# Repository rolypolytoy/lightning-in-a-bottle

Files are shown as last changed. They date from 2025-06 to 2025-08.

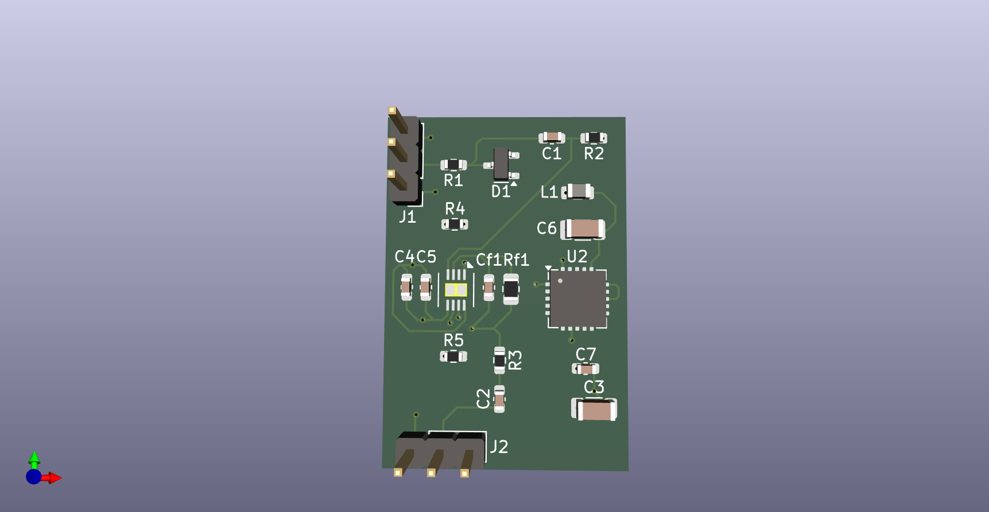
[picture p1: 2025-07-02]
csa.png

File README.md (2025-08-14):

# Lightning In A Bottle

Lightning in a bottle is an open-source, low-cost charge sensitive amplifier with several improvements over all existing commercial designs.

It has a >2x lower cost, a 750x greater gain, >5x greater bandwidth, >50% lower cost, and sub-5 dB lower SNR. Importantly- its real SNR will be higher since the gain is >750x, and since ADCs have noise, our gain will basically reduce that noise by 750x, and **so in real systems our CSA will have a much higher SNR than Cremat's module**, and thus this has no real 'weakness'. It also uses standard +5V as its power source rather than the weird +-6V-13V supplies the Cremat module needs.

It also uses commercial off-the-shelf components and so can be more easily and cheaply scaled than the Cremat CR-113 and other modules, whose components are proprietary and who may not ship to every country in the world in a timely manner.

Components:
- LMH6629SD, an ultra-low noise Op-Amp
- TPS7A3301RGW for power regulation
- Several miscellaneous ceramic capacitors, SMD resistors, inductors, and other generic components.

You can use a typical RC-CR pulse shaper or buy one from Cremat (might replace it soon but the CR-200-500ns arrived, so I don't need to make another one), but the specs of that are less important than the CSA setup. CSAs are better than transimpedance amplifiers for electron detection and nuclear research.

The [Cremat CR-113's datasheet](https://www.cremat.com/CR-113-R2.1.pdf) shows 18k electrons RMS baseline noise, 1.3 mV/pC gain and 30 electrons of noise RMS per pF, which means for the 0.01 microfarad AC coupled capacitor they show in their datasheet means they'll have around 300,000 electrons RMS of noise- which is a LOT of noise. Our SNR?

Op-amp voltage noise is 0.69 nV/√Hz (LMH6629), our feedback capacitor: Cf = 1pF, our feedback resistor: Rf = 10MΩ, our bandwidth: f = 1/(2π × Rf × Cf) = 1/(2π × 10MOhm × 1pF) = 15.9 kHz. Voltage noise is 0.69 nV/√Hz × √(15,900 Hz) = 0.69nV * 126 = 87 nV RMS voltage noise. Our gain is 1/Cf = 1/(1pF) = 1e12 V/C = 1000 mV/pC which is 750 times their gain. Our charge noise is thus 87nV / (1V/pC) = 87fC RMS, which is ~543,000 electrons, which is about a ~5 dB difference. 

Schematic file looks like:



PCB file looks like:



Gerbers, BOM and all manufacturing information is already there, and the project is in KiCAD's native file formats. It's a normal four-layer PCB with an estimated BOM of around $50/unit, which is less than half the price of a Cremat CR-113 module. 

## Charge Sensitive Amplifiers
Here's my attempt at explaining what a charge sensitive amplifier, written as a dialectic for my amusement (because who has the time to write a datasheet?)

A charge sensitive amplifier is basically just a capacitor around an op-amp. A capacitor is a thing which has capacitance, whereas an op-amp is something which makes voltage go up. I've made an informative schematic to fully get the concept across. 

OPAMPMAN

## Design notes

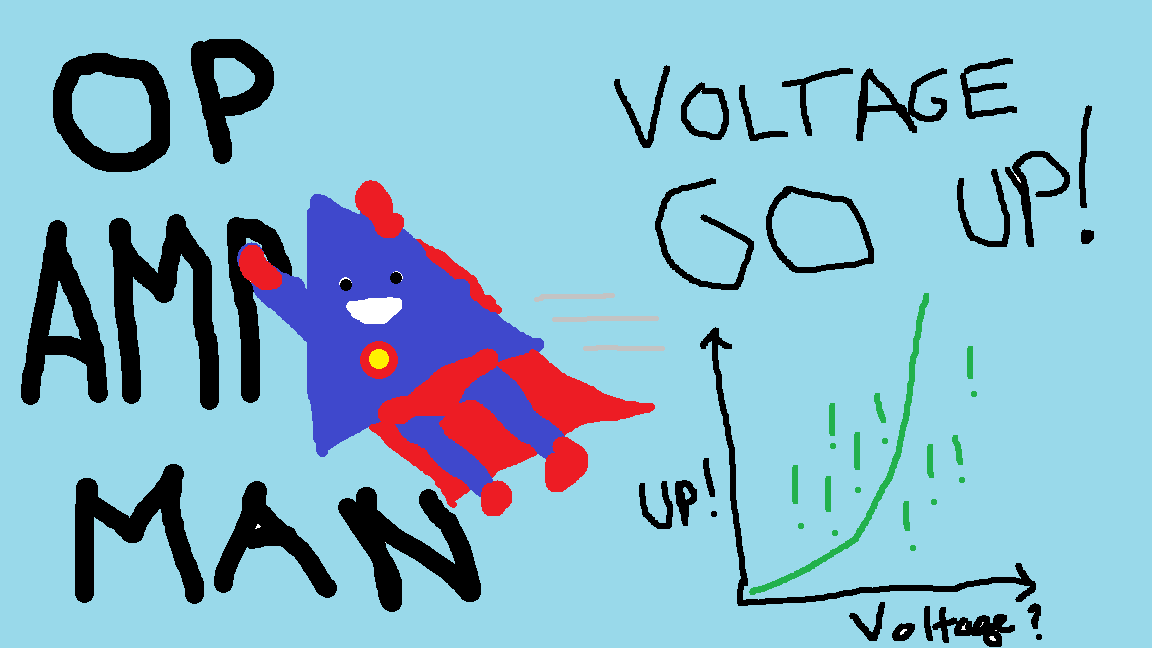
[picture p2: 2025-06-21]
OPAMPMAN.png

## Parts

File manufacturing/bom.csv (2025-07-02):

Id | Designator | Footprint | Quantity | Designation | MPN | Supplier/Notes
1 | C1,C2,C4 | C_0603_1608Metric | 3 | 100nF, 50V, X7R, ±10% | GCM188R71H104KA57D | Murata - 100nF 50V X7R 0603
2 | C3,C6 | C_1206_3216Metric | 2 | 10μF, 25V, X7R, ±10% | GRM31CR71E106KA12K | Murata - 10uF 25V X7R 1206
3 | U2 | Texas_RGW0020A_VQFN-20-1EP_5x5mm_P0.65mm_EP3.15x3.15mm_ThermalVias | 1 | TPS7A3301RGW | TPS7A3301RGWR | Texas Instruments - LDO Regulator (VERIFIED)
4 | C7 | C_0603_1608Metric | 1 | 1μF, 25V, X7R, ±10% | GCM188R71E105KA64D | Murata - 1uF 25V X7R 0603
5 | Cf1 | C_0603_1608Metric | 1 | 1pF, 50V, C0G/NP0, ±5% | GRM1885C1H1R0BA01D | Murata - 1pF 50V C0G/NP0 0603 precision cap
6 | U1 | WSON-8-1EP_3x3mm_P0.5mm_EP1.2x2mm | 1 | LMH6629SD/NOPB | LMH6629SD/NOPB | Texas Instruments - Op Amp (VERIFIED)
7 | R4,R5 | R_0603_1608Metric | 2 | 10KΩ, ±1%, 1/10W | RC0603FR-0710KL | Yageo - 10K ohm 1% 0603
8 | Rf1 | R_0805_2012Metric | 1 | 10MΩ, ±1%, 1/8W | CRCW080510M0FKEA | Vishay - 10M ohm 1% 0805
9 | C5 | C_0603_1608Metric | 1 | 1nF, 50V, X7R, ±10% | GCM188R71H102KA37D | Murata - 1nF 50V X7R 0603
10 | J2,J1 | PinHeader_1x03_P2.54mm_Vertical | 2 | Pin Header 1x03, 2.54mm pitch | PEC03SAAN | Sullins - 3-pin header 2.54mm pitch
11 | R3 | R_0603_1608Metric | 1 | 50Ω, ±1%, 1/10W | RC0603FR-0750RL | Yageo - 50 ohm 1% 0603
12 | D1 | SOT-23 | 1 | HSMS-2820 | HSMS-2820-TR1G | Broadcom/Avago - RF Schottky Diode (T&R packaging)
13 | L1 | L_0805_2012Metric | 1 | 10μH, ±20%, 0.5A | CB2012T100KR | Taiyo Yuden - 10uH 10% 0805 (VERIFIED - better tolerance)
14 | R2 | R_0603_1608Metric | 1 | 1MΩ, ±1%, 1/10W | RC0603FR-071ML | Yageo - 1M ohm 1% 0603
15 | R1 | R_0603_1608Metric | 1 | 1KΩ, ±1%, 1/10W | RC0603FR-071KL | Yageo - 1K ohm 1% 0603

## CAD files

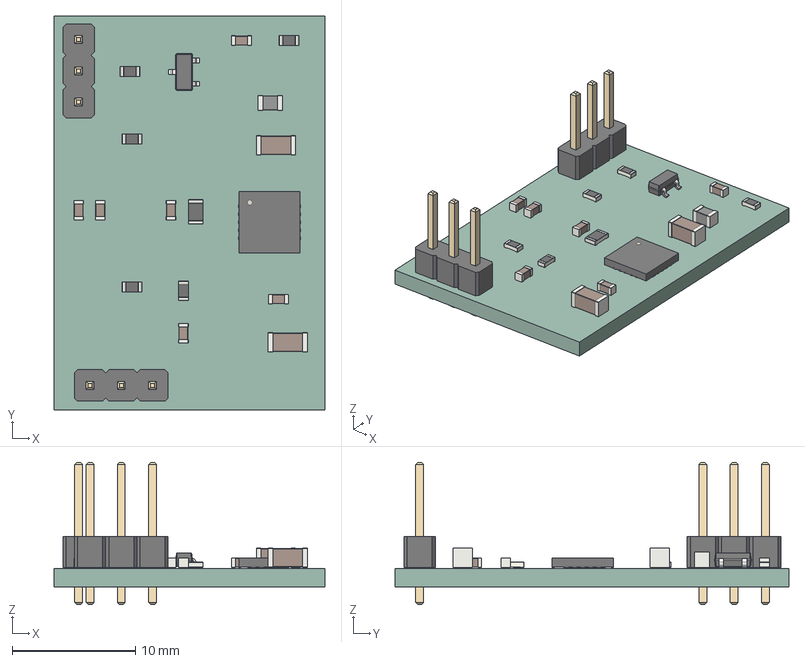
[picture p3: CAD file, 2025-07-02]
csa.step
22.0 x 32.0 x 11.5 mm
C_0603_1608Metric x 6
C_1206_3216Metric x 2
Texas_RGW0020A_VQFN-20-1EP_5x5mm_P0.65mm_EP3.15x3.15mm
R_0603_1608Metric x 5
R_0805_2012Metric
PinHeader_1x03_P2.54mm_Vertical x 2
SOT-23
L_0805_2012Metric
csa_PCB

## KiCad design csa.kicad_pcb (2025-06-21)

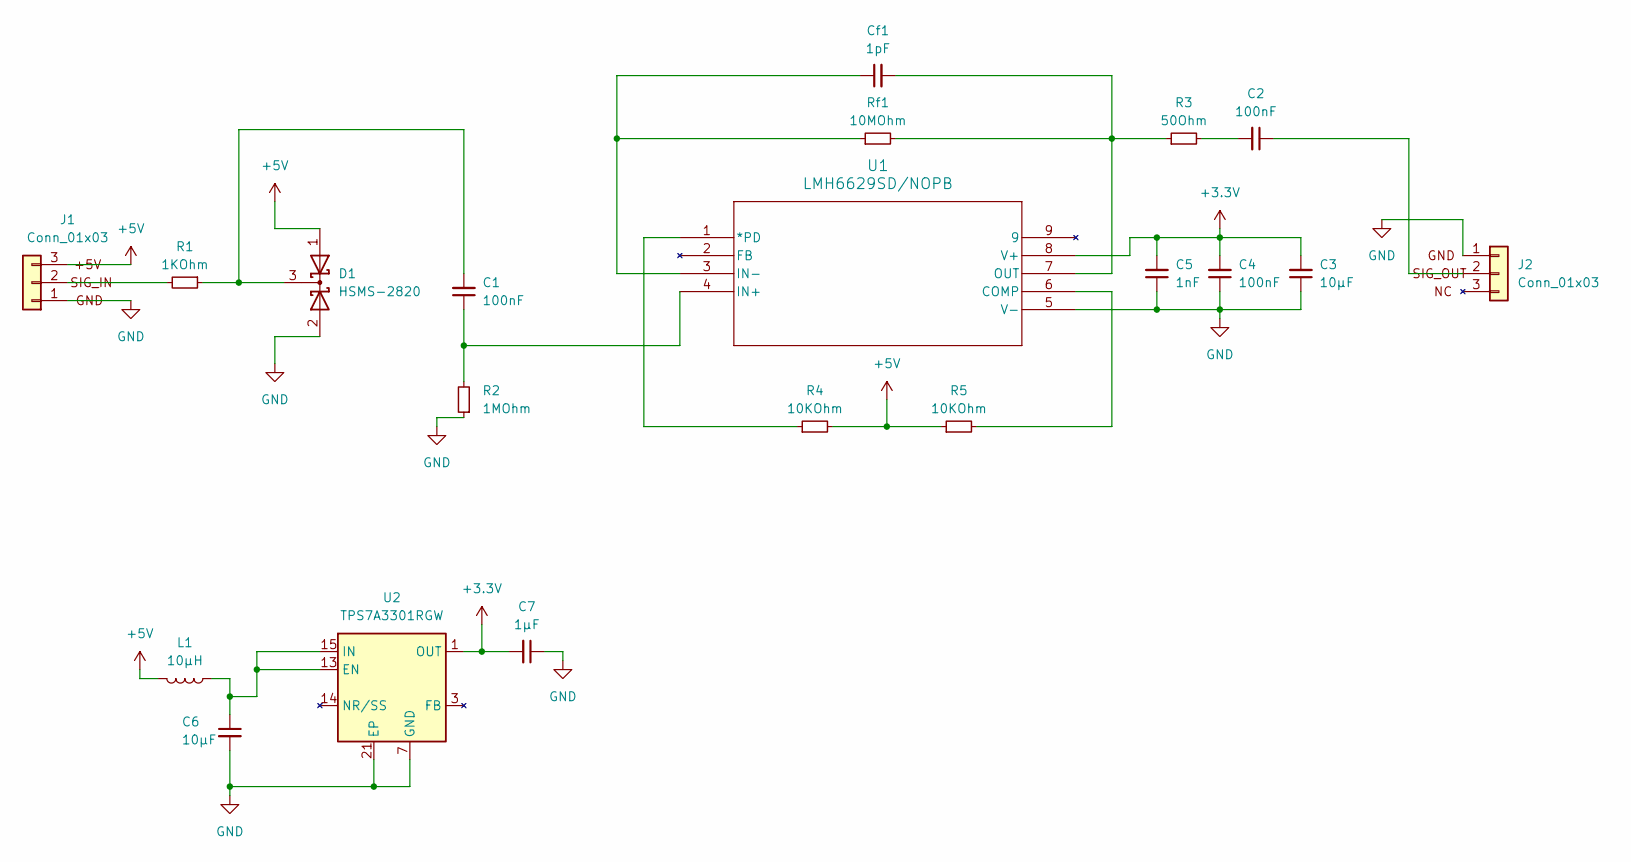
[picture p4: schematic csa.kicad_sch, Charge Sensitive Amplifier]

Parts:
C1, C2, C4: 100nF; C_0603_1608Metric
C3, C6: 10μF; C_1206_3216Metric
C5: 1nF; C_0603_1608Metric
C7: 1μF; C_0603_1608Metric
Cf1: 1pF; C_0603_1608Metric
D1: HSMS-2820; SOT-23
J1, J2: Conn_01x03; PinHeader_1x03_P2.54mm_Vertical
L1: 10μH; L_0805_2012Metric
R1: 1KOhm; R_0603_1608Metric
R2: 1MOhm; R_0603_1608Metric
R3: 50Ohm; R_0603_1608Metric
R4, R5: 10KOhm; R_0603_1608Metric
Rf1: 10MOhm; R_0805_2012Metric
U1: LMH6629SD/NOPB; WSON-8-1EP_3x3mm_P0.5mm_EP1.2x2mm
U2: TPS7A3301RGW; Texas_RGW0020A_VQFN-20-1EP_5x5mm_P0.65mm_EP3.15x3.15mm_Ther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

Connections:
+3.3V: C3.2, C4.2, C5.2, C7.2, U1.8 (V+), U2.1 (OUT), U2.20 (OUT)
+5V: D1.1 (A), J1.3, L1.2, R4.2, R5.1
GND: C3.1, C4.1, C5.1, C6.2, C7.1, D1.2 (A), J1.1, J2.1, R2.1, U1.5 (V-), U2.7 (GND), U2.21 (EP)
unnamed: C2.2, R3.2
unnamed: C1.2, D1.3 (K), R1.1
unnamed: J1.2, R1.2
unnamed: C2.1, J2.2
unnamed: R4.1, U1.1 (*PD)
unnamed: R5.2, U1.6 (COMP)
unnamed: C1.1, R2.2, U1.4 (IN+)
unnamed: Cf1.1, Rf1.1, U1.3 (IN-)
unnamed: Cf1.2, R3.1, Rf1.2, U1.7 (OUT)
unnamed: C6.1, L1.1, U2.13 (EN), U2.15 (IN), U2.16 (IN)

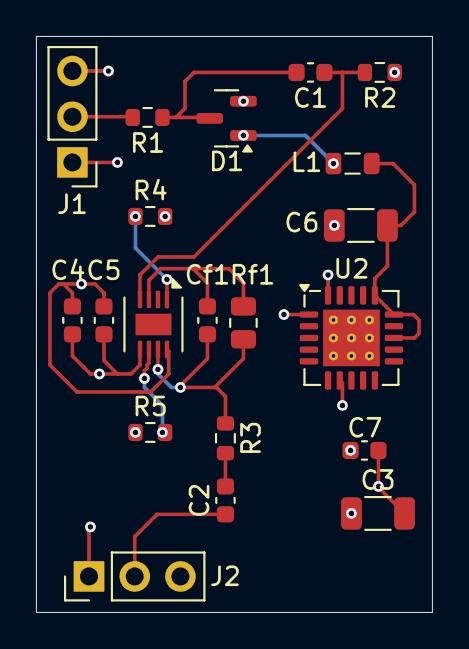
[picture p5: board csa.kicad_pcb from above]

Board: 4 copper layers, 22.0 x 32.0 mm, 20 parts (0 on the bottom side), 13 nets.
